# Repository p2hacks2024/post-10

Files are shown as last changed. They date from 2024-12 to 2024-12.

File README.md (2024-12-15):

# P2HACKS2024 アピールシート 

プロダクト名  
フラッシュ・フラストレーション & ラッフ・フラストレーション

コンセプト  
日々の不平不満を水に流してスッキリしよう！！

対象ユーザ  
現代社会にお疲れの皆さま

利用の流れ  
トイレ型ハードウェアに怒りや愚痴、不満を発散する  
↓  
トイレ型ハードウェアのレバーが回ってそれらを水に流す  
↓  
みんなから流れてきた愚痴をアプリケーションから閲覧、共感  

推しポイント  
アプリケーションだけでなくハードウェアを作成することで「水に流す（Flush）」という体験をより直接的に感じることができる

スクリーンショット(任意)  

toiletwater  
アプリアイコン  

スクリーンショット 2024-12-15 083532  
アプリのトップページ  

## 開発体制  

役割分担  
- Front  
  - KatsumaAkamatsu1137  
  - Atori-Ikeyama  
- Server
  - kokist  
  - Atori-Ikeyama  
- Hard  
  - sato1109  
  - tadaken0926  

開発における工夫した点  
- Front  
  - reactに挑戦した  
  - アニメーションを意識的に取り入れ
- Server  
  - rustという言語に挑戦した．
  - EC2にデプロイした
  - LLMを活用し，音声情報から感情の大きさの推定と文字起こしを同時に行なった．
- Hard  
  - センサやマイコン、ブレッドボードを内部に配置できるようモデルの調整を行った
  - ハードで実際にレバーを引く体験ができるよう、print-in-placeを採用した
  - レールを用いて組み立てを容易にした
  - 弁の開閉制御によって風量を調整し、発散した不満が大きいほどふくらみが大きくなるようにした
  - 15日に入ってから当初使用していた加速度センサ２つとラズパイ本体が15日に入ってから破損し使えなくなってしまったため、急遽状態の悪かったラズパイと超音波センサに切り替え実装を行った

## 開発技術 

システム構成
スクリーンショット 2024-12-15 9 50 53

利用したプログラミング言語  
JavaScript, CSS, Arduino, Python, Rust, 

利用したフレームワーク・ライブラリ  
Node.js, lucide-react, vite, react

その他開発に使用したツール・サービス
Docker, Git, Raspberry Pi 4, bambu studio, 3Dプリンタ, fusion360, AWS, EC2

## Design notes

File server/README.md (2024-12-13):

## エンドポイント
- Post：文章の登録．http://localhost:8080/submit
- Get：文章の取得と投稿時間の取得．http://localhost:8080/messages
- Put：「流そう」（いいねに近いもの）の数を増やす．http://localhost:8080/increment_flush/{id}

## 実行方法
- 以下のdockerコマンドでサーバを立ち上げる
```
docker compose up --build
```
- サーバへのcurlテストコマンド
```
curl -X POST -d "Hello, Docker!" http://localhost:8080/submit
curl http://localhost:8080/messages
```

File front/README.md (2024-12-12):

# React + Vite

This template provides a minimal setup to get React working in Vite with HMR and some ESLint rules.

Currently, two official plugins are available:

- [@vitejs/plugin-react](https://github.com/vitejs/vite-plugin-react/blob/main/packages/plugin-react/README.md) uses [Babel](https://babeljs.io/) for Fast Refresh
- [@vitejs/plugin-react-swc](https://github.com/vitejs/vite-plugin-react-swc) uses [SWC](https://swc.rs/) for Fast Refresh
# 実行方法
- 主に初回のコンテナ起動時、すでにあるイメージを使用してコンテナを起動する時に使用  
```docker compose up -d```

- Dockerfileやcompose.yamlを編集した時に使用  
  ```docker compose up -d --build```

- コンテナに入る時に使用 appはcompose.yamlのservicesの名前  
  ```docker compose exec app bash```

- コンテナを終了する時に使用  
  ```docker compose down```

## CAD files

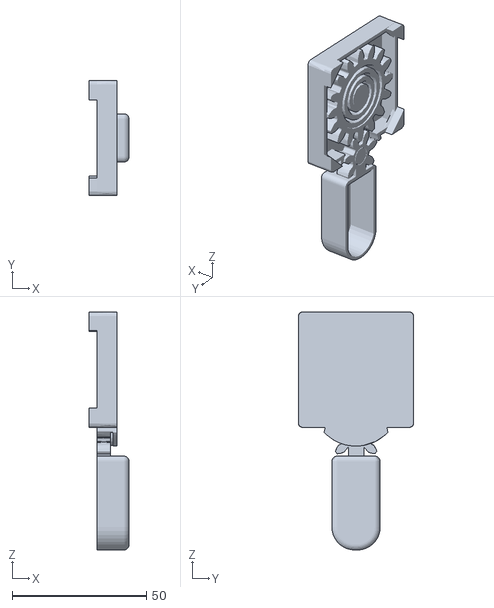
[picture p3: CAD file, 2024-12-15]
hardware/3dmodel/lever.stl
15.0 x 43.0 x 88.7

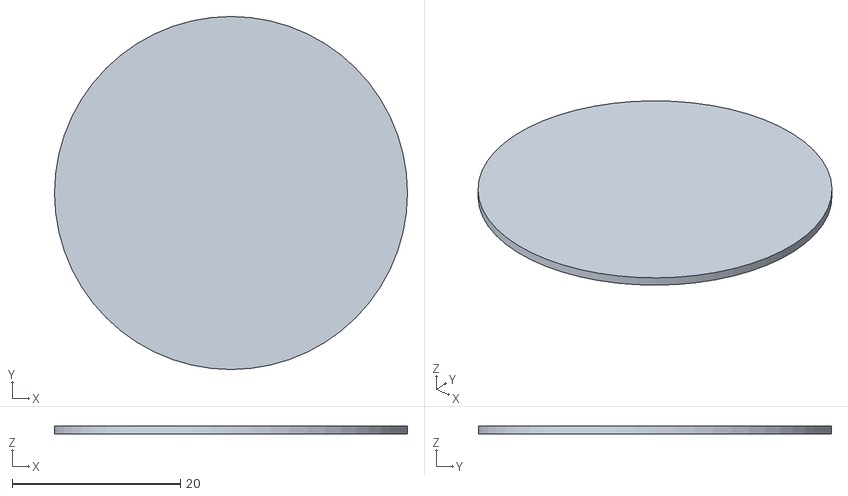
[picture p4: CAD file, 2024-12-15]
hardware/3dmodel/valve.stl
42.0 x 42.0 x 1.00

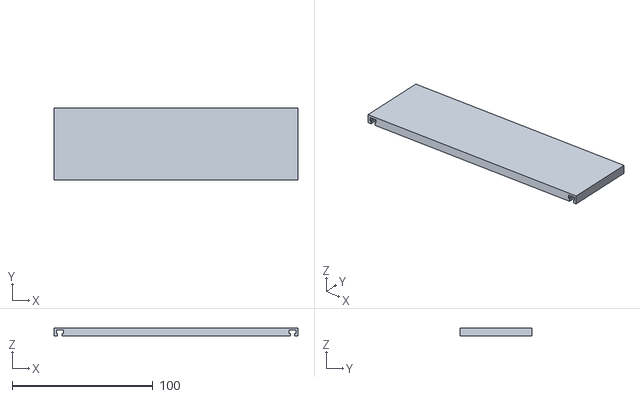
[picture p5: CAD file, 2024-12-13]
hardware/3dmodel/dryerbox_upperlid.stl
173.1 x 50.9 x 6.00

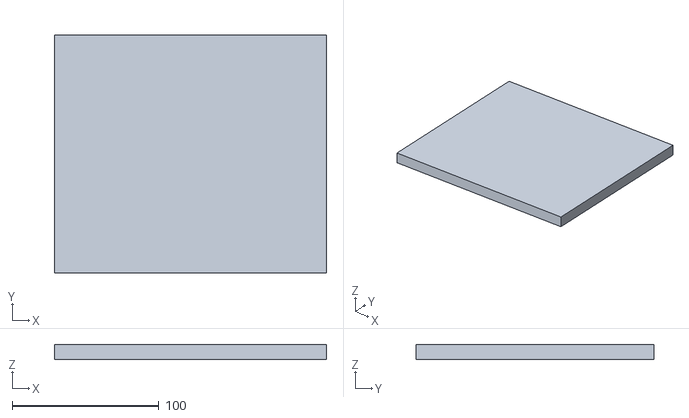
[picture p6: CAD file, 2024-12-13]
hardware/3dmodel/miconbox_lid.stl
185.1 x 162.0 x 10.0

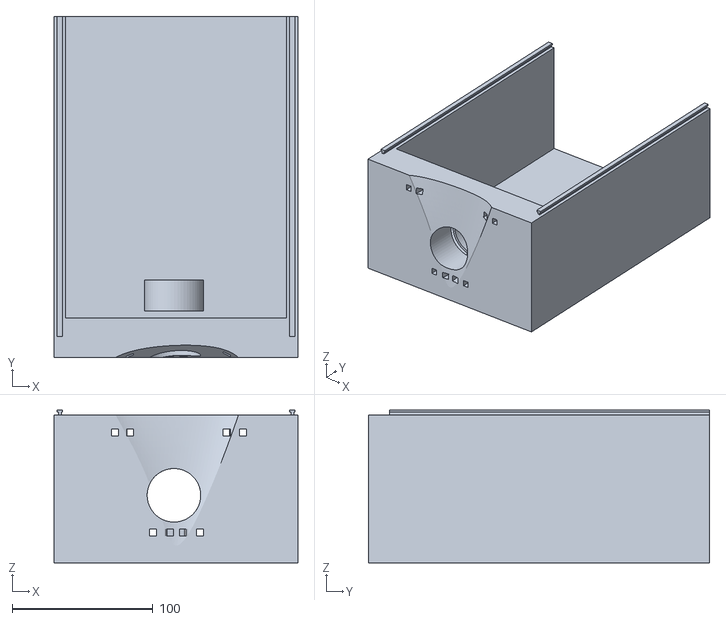
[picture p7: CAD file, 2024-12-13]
hardware/3dmodel/dryerbox.stl
173.1 x 242.0 x 108.5

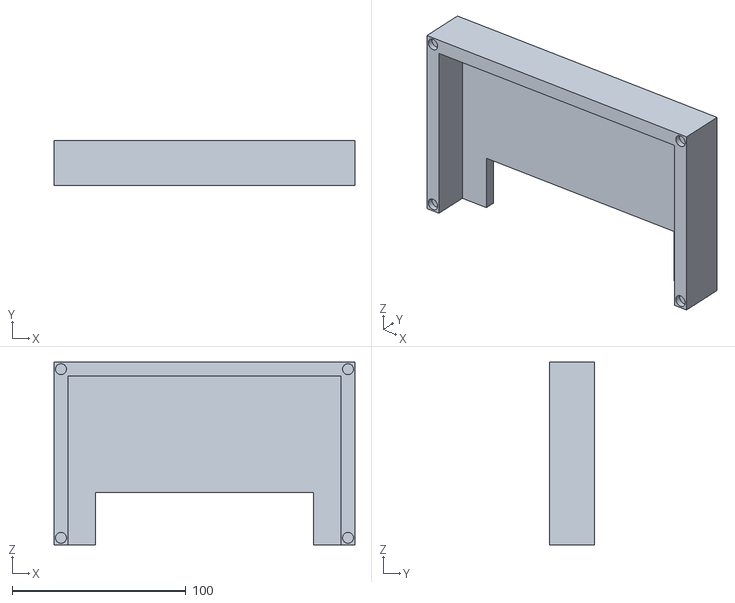
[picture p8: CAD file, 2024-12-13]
hardware/3dmodel/dryerbox_lid.stl
173.1 x 26.0 x 105.0

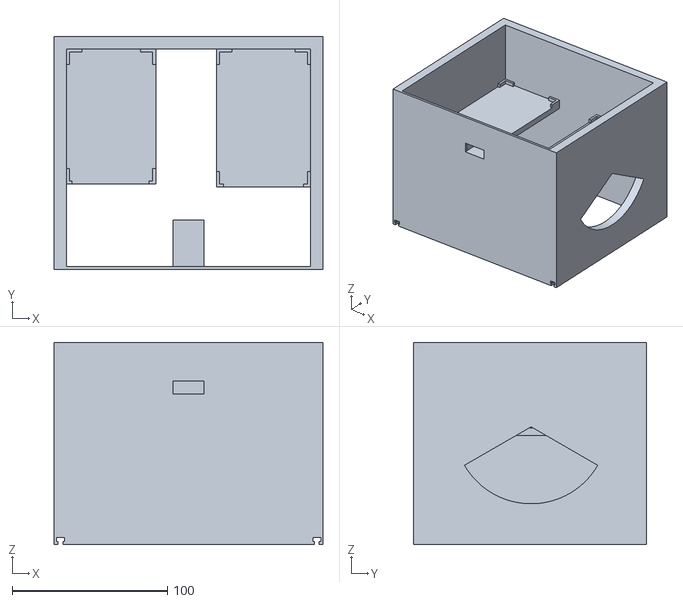
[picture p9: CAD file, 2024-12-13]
hardware/3dmodel/miconbox.stl
173.1 x 150.0 x 130.0

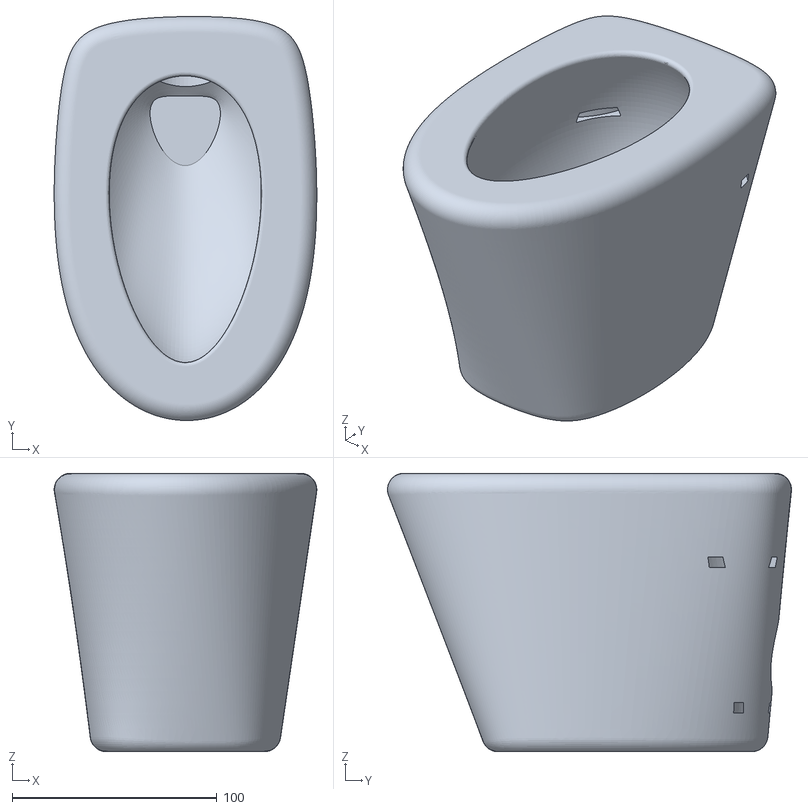
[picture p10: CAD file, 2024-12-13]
hardware/3dmodel/toiletbody.stl
128.3 x 197.3 x 136.0

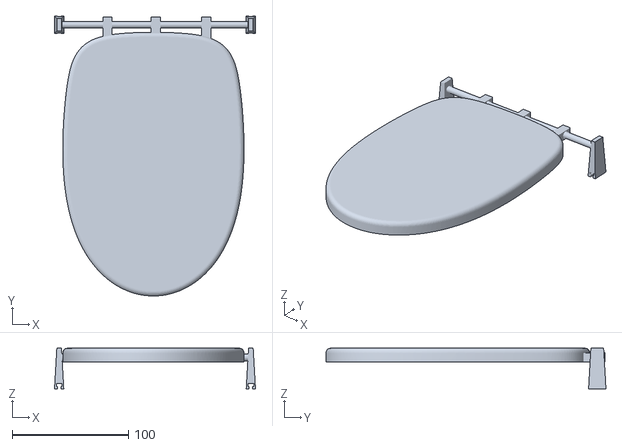
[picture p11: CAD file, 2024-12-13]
hardware/3dmodel/toiletlid.stl
173.0 x 241.0 x 35.0

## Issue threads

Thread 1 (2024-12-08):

センサの調査

Atori-Ikeyama, 2024-12-08:
- レバーを引いたことを検知できるか
- フタを開けたことを検知できるか

tadaken0926, 2024-12-08:
https://hellobreak.net/raspberry-pi-sensor-kinds/
ジャイロ、加速度、赤外線、タッチ、圧力辺り？

tadaken0926, 2024-12-08:
レバー　照度センサ

tadaken0926, 2024-12-08:
加速度センサが丸い

tadaken0926, 2024-12-08:
https://devcat.jp/post/08_pi_usb_mic/
ラズパイでUSBマイク動かす方法

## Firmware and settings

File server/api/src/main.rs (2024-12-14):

use actix_web::{web, App, HttpServer, Responder, HttpResponse, post, get, put};
use rusqlite::{params, Connection, Result};
use serde::{Serialize, Deserialize};
use std::sync::{Arc, Mutex};

#[derive(Serialize)]
struct Message {
    id: i32,
    content: String,
    timestamp: String,
    flush: i32,
    score: i32,
}

#[derive(Deserialize)]
struct Body {
    content: String,
    score: i32,
}

// SQLiteデータベースを初期化
fn init_db() -> Result<Connection> {
    let conn = Connection::open("messages.db")?;
    conn.execute(
        "CREATE TABLE IF NOT EXISTS messages (
            id INTEGER PRIMARY KEY AUTOINCREMENT,
            content TEXT NOT NULL,
            timestamp TEXT NOT NULL,
            flush INTEGER DEFAULT 0,
            score INTEGER DEFAULT 0
        )",
        [],
    )?;
    Ok(conn)
}

// POSTエンドポイント: メッセージを保存
#[post("/submit")]
async fn submit(
    data: web::Data<Arc<Mutex<Connection>>>,
    body: web::Json<Body>,
) -> impl Responder {
    let conn = data.lock().unwrap();
    let now = chrono::Local::now().to_rfc3339();

    match conn.execute(
        "INSERT INTO messages (content, flush, timestamp, score) VALUES (?1, ?2, ?3, ?4)",
        params![body.content, 0, now, body.score],
    ) {
        Ok(_) => HttpResponse::Ok().body("Message saved successfully!"),
        Err(e) => {
            eprintln!("Error inserting message: {}", e);
            HttpResponse::InternalServerError().body("Failed to save message")
        }
    }
}

// GETエンドポイント: メッセージを取得
#[get("/messages")]
async fn get_messages(data: web::Data<Arc<Mutex<Connection>>>) -> impl Responder {
    let conn = data.lock().unwrap();
    let mut stmt = match conn.prepare("SELECT id, content, timestamp, flush, score FROM messages") {
        Ok(stmt) => stmt,
        Err(e) => {
            eprintln!("Error preparing statement: {}", e);
            return HttpResponse::InternalServerError().body("Failed to retrieve messages");
        }
    };

    let messages_iter = stmt.query_map([], |row| {
        Ok(Message {
            id: row.get(0)?,
            content: row.get(1)?,
            timestamp: row.get(2)?,
            flush: row.get(3)?,
            score: row.get(4)?,
        })
    });

    match messages_iter {
        Ok(messages) => {
            let messages: Vec<Message> = messages.filter_map(Result::ok).collect();
            HttpResponse::Ok().json(messages)
        }
        Err(e) => {
            eprintln!("Error querying messages: {}", e);
            HttpResponse::InternalServerError().body("Failed to retrieve messages")
        }
    }
}

// PUTエンドポイント: flushの値を一つあげる
#[put("/increment_flush/{id}")]
async fn increment_flush(
    data: web::Data<Arc<Mutex<Connection>>>,
    id: web::Path<i32>,
) -> impl Responder {
    let conn = data.lock().unwrap();

    match conn.execute(
        "UPDATE messages SET flush = flush + 1 WHERE id = ?1",
        params![*id],
    ) {
        Ok(_) => HttpResponse::Ok().body("Flush value incremented successfully!"),
        Err(e) => {
            eprintln!("Error updating flush value: {}", e);
            HttpResponse::InternalServerError().body("Failed to increment flush value")
        }
    }
}

#[actix_web::main]
async fn main() -> std::io::Result<()> {
    // データベースを初期化
    let conn = init_db().unwrap();
    let conn = Arc::new(Mutex::new(conn)); // Arc<Mutex<T>> で共有可能にラップ

    // Actix-webサーバーを起動
    HttpServer::new(move || {
        App::new()
            .app_data(web::Data::new(conn.clone())) // Arc をクローン
            .service(submit)
            .service(get_messages)
            .service(increment_flush)
    })
    .bind(("0.0.0.0", 8080))?
    .run()
    .await
}

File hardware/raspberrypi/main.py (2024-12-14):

import sys
import time
import smbus
from accl_record import record_audio, AcclRecord
from analyse_audio import AnalyseAudio
import RPi.GPIO as GPIO
import pygame  # 音声再生用

# サーボ制御用の関数（角度と速度を調整）
def move_servo(pin, angle, speed):
    pwm = GPIO.PWM(pin, 50)  # 50HzのPWM信号
    pwm.start(0)  # 初期化

    # 現在の角度から目標角度までゆっくり動かす
    current_angle = 60
    step = 1 if angle > current_angle else -1  # 角度の進む方向を決定
    for position in range(current_angle, angle + step, step):
        duty_cycle = (position / 180.0) * 10 + 2.5  # 角度をDuty比に変換
        pwm.ChangeDutyCycle(duty_cycle)
        time.sleep(speed)  # スピードに応じて待機時間を調整

    pwm.stop()

# 音声再生用の関数
def play_audio(file_path):
    pygame.mixer.init()
    pygame.mixer.music.load(file_path)
    pygame.mixer.music.play()
    while pygame.mixer.music.get_busy():  # 再生が終了するまで待機
        time.sleep(0.1)

def main():
    # GPIOの設定
    GPIO.setmode(GPIO.BCM)
    GPIO.setup(9, GPIO.OUT)  # サーボモーターのピン

    # センサーのI2Cアドレス
    SENSOR_1_ADDR_ACCL = 0x19  # 実物センサーの加速度アドレス
    SENSOR_2_ADDR_ACCL = 0x18  # 仮想センサーの加速度アドレス

    # I2Cバスのインスタンス
    bus_sensor_1 = smbus.SMBus(3)  # 実物センサーはバス3
    bus_sensor_2 = smbus.SMBus(1)  # 仮想センサーはバス1

    # センサーの初期化
    accl_record_1 = AcclRecord(bus_sensor_1, SENSOR_1_ADDR_ACCL)
    accl_record_2 = AcclRecord(bus_sensor_2, SENSOR_2_ADDR_ACCL)

    # 録音が完了したかのフラグ
    audio_recorded = False

    # 録音データの解析
    analyser = AnalyseAudio()
    analysis_result = None  # 解析結果を保持する変数

    while True:
        # 1つ目のセンサーからデータ取得
        x1, y1, z1 = accl_record_1.BMX055_Accl()
        print(f"Sensor 1 Accl= {x1:.2f}, {y1:.2f}, {z1:.2f}")

        # 2つ目のセンサーからデータ取得
        x2, y2, z2 = accl_record_2.BMX055_Accl()
        print(f"Sensor 2 Accl= {x2:.2f}, {y2:.2f}, {z2:.2f}")

        # 録音がまだで、z1が0.85未満なら録音を開始
        if not audio_recorded and z1 < 0.85:
            record_audio()
            audio_recorded = True  # 一度録音したのでフラグを立てる
            analysis_result = analyser.analyse('output.wav')
            print(f"Audio Analysis Result: {analysis_result}")

        # z2が0.70未満になったらサーボを動かす
        if audio_recorded and z2 < 0.70:
            if analysis_result is not None:
                intensity = analysis_result.intensity_of_emotion
                # 感情の強度に応じてサーボの角度と速度を調整
                if intensity <= 3:
                    angle =65   # 感情が弱い場合は5度
                    speed = 0.2  # ゆっくり動かす
                elif 4 <= intensity <= 6:
                    angle =85   # 中程度の感情の場合は25度
                    speed = 0.1  # 通常の速度
                else:
                    angle = 110  # 感情が強い場合は50度
                    speed = 0.05  # 早く動かす
                move_servo(9, angle, speed)
                print(f"Servo moved to {angle}° with speed {speed}s per step, based on emotion intensity {intensity}.")
                
                # 音声ファイルを再生
                play_audio("toilet_sound.wav")
            break  # 条件を満たしたらループ終了

        print("--------------------------------------")
        time.sleep(1)

if __name__ == "__main__":
    try:
        main()
    except KeyboardInterrupt:
        print("\n終了中...")
        GPIO.cleanup()  # GPIOピンのクリーンアップ

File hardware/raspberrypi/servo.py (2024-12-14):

import RPi.GPIO as GPIO
import time

# GPIO設定
SERVO_PIN = 9  # サーボモーターを接続したGPIOピン
GPIO.setmode(GPIO.BCM)  # GPIO番号の指定方法をBCMに設定
GPIO.setup(SERVO_PIN, GPIO.OUT)  # サーボ用ピンを出力モードに設定

# サーボ制御用PWMの設定
pwm = GPIO.PWM(SERVO_PIN, 50)  # 50HzのPWM信号（サーボ用）
pwm.start(0)  # PWM信号を開始（初期値は0）

def set_angle(angle):
    """
    サーボを指定した角度に動かす関数
    :param angle: サーボの目標角度（0〜180度）
    """
    duty = (angle / 18.0) + 2.5  # 角度をDuty比に変換
    pwm.ChangeDutyCycle(duty)
    time.sleep(0.5)  # サーボが動くのを待機
    pwm.ChangeDutyCycle(0)  # 信号を停止してサーボのバズ音を防ぐ

try:
    while True:
        # サーボを0度に動かす
        print("Moving to 0 degrees")
        set_angle(60)
        time.sleep(1)

        # サーボを90度に動かす
        print("Moving to 90 degrees")
        set_angle(110)
        time.sleep(1)

        # サーボを180度に動かす
        print("Moving to 180 degrees")
        set_angle(120)
        time.sleep(1)

except KeyboardInterrupt:
    print("\nプログラム終了中...")

finally:
    pwm.stop()  # PWMを停止
    GPIO.cleanup()  # GPIOピンをリセット

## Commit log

2024-12-10 update gitignoreの修正
2024-12-11 Update README.md
    実行方法の追加
2024-12-12 Update README.md
    誤字修正
2024-12-12 Add Raspberry Pi audio recording and analysis functionality
2024-12-12 Refactor Raspberry Pi sensor handling and audio analysis; add class-based structure for accelerometer data and update dependencies
2024-12-13 arduinoで人感センサの制御
2024-12-13 z1とz2の加速度を独立させ、z1で録音、z2でサーボの制御をはじめるように変更
2024-12-13 add 3dmodels
    [dryerbox.stl, dryerbox_lid.stl, dryerbox_upperlid.stl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]
2024-12-14 Update README.md
    改行の修正
2024-12-14 Add to control servo by intensity_of_emotion
2024-12-14 Add servo control by intensity_of_emotion
2024-12-14 サーボが動いた後にトイレの流れる音を流す
2024-12-14 Add hc04 sensor and test code
2024-12-14 add sample data to messages table
2024-12-14 Release focus state and switch to system using API
